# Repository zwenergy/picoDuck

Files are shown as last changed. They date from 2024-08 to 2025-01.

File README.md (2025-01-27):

# picoDuck
An open-source RP2040-based flash cart for the Mega Duck aka Cougar Boy.
The RP2040 acts as the ROM chip of the cart.

## Software Side Single ROM FW
In order to load a game onto the cartridge, you first have a "convert" a ROM to a UF2 file.

### Using the Online Patcher
You can use the [online patcher tool](https://zwenergy.github.io/picoDuckSingleROMPatch/index.html) to patch in a ROM into the ROM-less base UF2 firmware.
You can find the latest ROM-less base UF2 firmware in the releases tab.
Use this as the UF2 file and any Mega Duck ROM in the ROM file (max. ROM file size is 131072 bytes).

### Building a FW from Scratch

**Requirements:**
1. Python
2. CMake
3. RP2040 C SDK installed and paths set up

### Single ROM
Steps:

1. Use the bin2c.py script to convert a ROM file to a C-array. Usage: `bin2c.py ROMFILE rom.h`. Place the genereated `rom.h` file in the root of code directory, beside main.c.
2. Run `make` in the code directory.
3. Connect the Raspberry Pi Pico to the computer while holding down the BOOTSEL button.
4. Drag and drop the newly generated .uf2 file onto the Pico.

## Software Side Multi ROM FW
You can also find a basic multi ROM FW in this repo with 10 slots by default.
It uses the [Mega Duck cart menu](https://github.com/bbbbbr/megaduck_cartmenu) by [bbbbbr](https://github.com/bbbbbr).
All slots have a fixed size of 131072 bytes.

A pre-compiled base FW UF2 file for the 10 slot multi ROM FW with the cart menu can be find in the releases tab. 
Use the [online patcher tool](https://zwenergy.github.io/picoDuckMultiROMPatch/index.html) to insert ROMs and set labels in the menu.

## Hardware Side
### BOM
| **Reference** | **Value**| **Links**
|---|---|---|
| U2, U3, U4, U5 | TXB0108PWR |[LCSC](https://www.lcsc.com/product-detail/Translators-Level-Shifters_Texas-Instruments-TXB0108PWR_C53406.html)|
| U6 | Raspberry Pi Pico ||
| Q1 | N-Channel MOSFET (SOT-23) |[LCSC](https://www.lcsc.com/product-detail/MOSFETs_Jiangsu-Changjing-Electronics-Technology-Co-Ltd-CJ2302_C2910175.html)|
| R1 | 1 kOhm resistor (0805) |[LCSC](https://www.lcsc.com/product-detail/Chip-Resistor-Surface-Mount_UNI-ROYAL-Uniroyal-Elec-0805W8F1001T5E_C17513.html)|
| R2 | 470 kOhm resistor (0805) |[LCSC](https://www.lcsc.com/product-detail/Chip-Resistor-Surface-Mount_UNI-ROYAL-Uniroyal-Elec-0805W8F4703T5E_C17709.html)|

### PCB
The PCB can be ordered using the Gerber files. A width of **1.2 mm** should be chosen with ENIG surface.

## Shell
A 3D printable shell for the cart can be found in the folder "shell".

## Disclaimer
**Use the files and/or schematics to build your own board at your own risk**.
This board works fine for me, but it's a simple hobby project, so there is no liability for errors in the schematics and/or board files.
**Use at your own risk**.

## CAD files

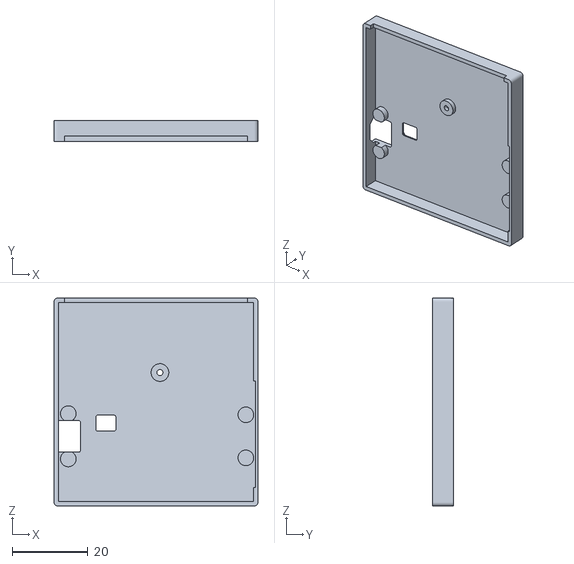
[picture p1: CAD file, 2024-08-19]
shell/top.stl
54.0 x 5.50 x 55.0

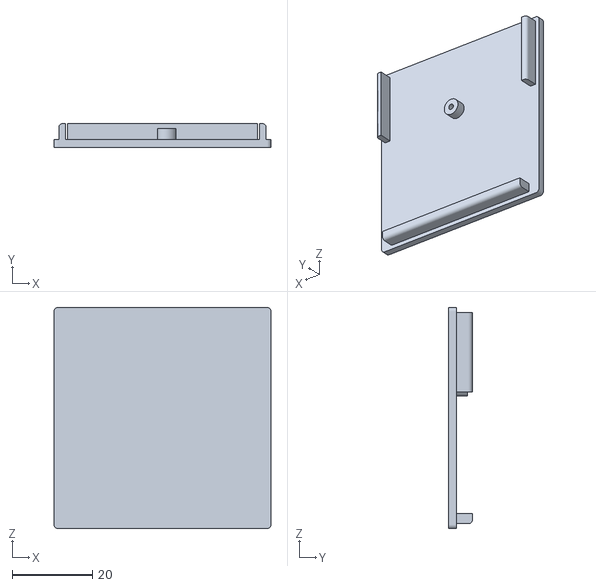
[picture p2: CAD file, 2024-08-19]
shell/bottom.stl
54.0 x 6.00 x 55.0

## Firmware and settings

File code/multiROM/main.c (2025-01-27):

// Reset pulse after loading?
// (not recommended for the MD laptop)
#define RSTPULSE

// CRC check len
#define CRCLEN 65536

#include "pico/stdlib.h"
#include <stdlib.h>

#include "rom_menu.h"
#include "roms.h"

// Include string.h for memcpy
#include <string.h>

// Pin Definitions.
#define A0 0
#define A1 1
#define A2 2
#define A3 3
#define A4 4
#define A5 5
#define A6 6
#define A7 7
#define A8 8
#define A9 9
#define A10 10
#define A11 11
#define A12 12
#define A13 13
#define A14 14
#define A15 15

#define D0 16
#define D1 17
#define D2 18
#define D3 19
#define D4 20
#define D5 21
#define D6 22
#define D7 26

#define NWR 27
#define RST 28

#define DATAOFFSETLOW 16
#define DATAOFFSETHIGH 26

#define LED_INT 25

#define RSTMS 100

// Bit masks.
#define ADDRMASK 0b00000000000000001111111111111111
#define DATAMASK 0b00000100011111110000000000000000
#define LOWDATAMASK 0b00000000011111110000000000000000
#define NWRMASK  0b00001000000000000000000000000000
#define RSTMASK  0b00010000000000000000000000000000
#define A15MASK  0b00000000000000001000000000000000

#define DATAMASKLOW  0b01111111
#define DATAMASKHIGH 0b10000000

// Reset function.
void doReset() {
  gpio_set_dir( RST, GPIO_OUT );
  gpio_put( RST, 1 );
  sleep_ms( RSTMS );
  gpio_put( RST, 0 );
  
  gpio_pull_down( RST );
  
  // Set RST pin back to INPUT, so we can use GPIO_PUT as non-masked.
  gpio_set_dir( RST, GPIO_IN );
}


void __not_in_flash_func( initGPIO() ) {
  // Set all pins to input first.
  gpio_init_mask( ADDRMASK | DATAMASK | NWRMASK );
  gpio_set_dir_in_masked( ADDRMASK | DATAMASK | NWRMASK );
  
  // Except the LED.
  gpio_init( LED_INT );
  gpio_set_dir( LED_INT, GPIO_OUT );
  
  // And reset.
  gpio_init( RST );
  gpio_set_dir( RST, GPIO_OUT );
}

// CRC32
uint32_t crc32(uint8_t* data, uint32_t length ) {  
  uint32_t byte, crc, mask;
  uint32_t cnt = 0;

  crc = 0xFFFFFFFF;
  while ( cnt < length ) {
    byte = data[ cnt ];
    crc = crc ^ byte;
    for ( int32_t j = 7; j >= 0; j-- ) {
      mask = -( crc & 1 );
      crc = ( crc >> 1 ) ^ ( 0xEDB88320 & mask );
    }
    cnt++;
  }
  
  return ~crc;
}

void __not_in_flash_func( handleMD1() ) {
  // Initial bank.
  uint8_t* rombank = rom;
  
  // Start endless loop.
  while( 1 ) {
    uint32_t data = gpio_get_all();
    uint32_t addr = data & ADDRMASK;
    uint32_t wr = !( data & NWRMASK );
    uint32_t a15 = ( data & A15MASK );
    
    if ( !a15 && !wr ) {
      // Data output.
      gpio_set_dir_out_masked( DATAMASK );
      
      // Get data byte.
      uint8_t rombyte;
      rombyte = rombank[ addr ];
      
      uint32_t gpiobyte = 0;
      gpiobyte |= ( ( rombyte & DATAMASKLOW ) >> 0 ) << DATAOFFSETLOW;
      gpiobyte |= ( ( rombyte & DATAMASKHIGH ) >> 7 ) << DATAOFFSETHIGH;
      
      // And put it out.
      gpio_put_all( gpiobyte );
      
      continue;
      
    } else {
      // Data input.
      gpio_set_dir_in_masked( DATAMASK );
    }
    
    if ( wr ) {
      uint32_t writeData;
      // Bank change?
      if ( addr == 0xB000 ) {
            
        writeData = ( data & LOWDATAMASK ) >> DATAOFFSETLOW;
        if ( writeData == 0 ) {
          rombank = rom;
        } else if ( writeData == 1 ) {
          rombank = rom + 32768;
        }
      }
    }
  }
}

void __not_in_flash_func( handleMD2() ) {
  // Initial bank.
  uint8_t* rombank = rom;
  
  // Start endless loop.
  while( 1 ) {
    uint32_t data = gpio_get_all();
    uint32_t addr = data & ADDRMASK;
    uint32_t wr = !( data & NWRMASK );
    uint32_t a15 = ( data & A15MASK );
    
    if ( !a15 && !wr ) {
      // Data output.
      gpio_set_dir_out_masked( DATAMASK );
      
      // Get data byte.
      uint8_t rombyte;
      // Check if lower part
      if ( addr < 16384 ) {
        rombyte = rom[ addr ];
      } else {
        rombyte = rombank[ addr ];
      }
      
      uint32_t gpiobyte = 0;
      gpiobyte |= ( ( rombyte & DATAMASKLOW ) >> 0 ) << DATAOFFSETLOW;
      gpiobyte |= ( ( rombyte & DATAMASKHIGH ) >> 7 ) << DATAOFFSETHIGH;
      
      // And put it out.
      gpio_put_all( gpiobyte );
      
      continue;
      
    } else {
      // Data input.
      gpio_set_dir_in_masked( DATAMASK );
    }
    
    if ( wr ) {
      uint32_t writeData;
      // Bank change?
      if ( addr == 0x001 ) {
        // Type 2
        writeData = ( ( data & LOWDATAMASK ) >> DATAOFFSETLOW )& 0b111;
        
        if ( writeData ) {
          rombank = rom + ( writeData - 1 ) * 16384;
        } else {
          rombank = rom; 
        }
        
        continue;
        
      }
    }
  }
}


void __not_in_flash_func( handleMenu() ) {
  // Initial bank.
  uint8_t* rombank = rom;
  
  // Start endless loop.
  while( 1 ) {
    uint32_t data = gpio_get_all();
    uint32_t addr = data & ADDRMASK;
    uint32_t wr = !( data & NWRMASK );
    uint32_t a15 = ( data & A15MASK );
    
    if ( !a15 && !wr ) {
      // Data output.
      gpio_set_dir_out_masked( DATAMASK );
      
      // Get data byte.
      uint8_t rombyte;
      rombyte = rombank[ addr ];
      
      uint32_t gpiobyte = 0;
      gpiobyte |= ( ( rombyte & DATAMASKLOW ) >> 0 ) << DATAOFFSETLOW;
      gpiobyte |= ( ( rombyte & DATAMASKHIGH ) >> 7 ) << DATAOFFSETHIGH;
      
      // And put it out.
      gpio_put_all( gpiobyte );
      
      continue;
      
    } else {
      // Data input.
      gpio_set_dir_in_masked( DATAMASK );
    }
    
    if ( wr ) {
      uint32_t writeData;
      // Bank change?
      if ( addr == 0x002 ) {
        // Read again.
        data = gpio_get_all();
        // Menu item choose. We load the new ROM into RAM.
        writeData = ( ( data & LOWDATAMASK ) >> DATAOFFSETLOW ) - 1;
        
        memcpy( rom, romStorage + ( writeData * ROMENTRYSIZE ), ROMENTRYSIZE );
        
        // Calc. CRC
        uint32_t crc = crc32( rom, CRCLEN );
        
        // MD1 ROM?
        if ( crc == 0x35FB1616 || // Puppet Knight
             crc == 0xCD2730AC ) { // Suleiman's Treasure
          doReset();
          handleMD1();
          
        } else {
          // All other known ROMs are no banking or MD2 banking.
          doReset();
          handleMD2();
        }
      }
    }
  }
}

void main() {
  // Set higher freq.
  set_sys_clock_khz(250000, true);
  
  // Init GPIO.
  initGPIO();
  
  // Turn on LED.
  gpio_put( LED_INT, 1 );
  
  #ifdef RSTPULSE
  // Reset.
  doReset();
  #endif
  
  handleMenu();
}

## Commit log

2024-08-18 Added Gerber files.
2024-08-19 Added 3D printable shell STLs.
    [bottom.stl, top.stl]
2024-09-01 Fix bank bug and speed up.
    [main.c]
2025-01-30 Fixed MD1 address bug and replaced banking code for single ROM.
    [main.c]
